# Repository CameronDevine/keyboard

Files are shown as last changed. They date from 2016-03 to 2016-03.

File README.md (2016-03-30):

#The Emoji Keyboard#

##FAQ##

If you run into any problems using the keyboard normally, please see the FAQ located [here](FAQ.md).

##Reprograming##

###Drivers###

This keyboard is an Adafruit Trinket 5V with three buttons and missing a couple of LEDs. If you would like to try to reprogram the board, the webpage [here](https://learn.adafruit.com/introducing-trinket/introduction) will guide you through installing the necessary drivers. And give a general introduction to programming the board.

###Bootloader###

Once the correct drivers are installed, and you are ready to program the board, the bootloader needs to be activated. On the Adafruit Trinket there is a button supplied for this purpose. On the keyboard there are two ways this can be done.

####Method 1####

One way to activate the bootloader is to unplug the USB cable and plug it back in. This will start the bootloader for a couple seconds before the board enters its keyboard mode.

####Method 2####

The other method is to short the reset (Rst) and ground (Gnd) pins. This second method has the exact same effect as the reset button on the Trinket.

###Libraries###

Two libraries are needed for the keyboard code to run. One is the built in EEPROM library and the other is the Trinket Keyboard library located [here](https://github.com/adafruit/Adafruit-Trinket-USB/archive/master.zip).

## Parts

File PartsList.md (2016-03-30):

#Parts List#

| location | DigiKey P/N |
|---|---|
| C1 | 732-8788-1-ND |
| D1 | 1N4148FS-ND |
| D2 | 1N4148FS-ND |
| IC1 | ATTINY85-20PU-ND |
| P1 | WM17115-ND |
| R1 | CF14JT68R0CT-ND |
| R2 | CF14JT68R0CT-ND |
| R3 | CF14JT1K50CT-ND |
| SW1 | 679-2428-ND |
| SW2 | 679-2428-ND |
| SW3 | 679-2428-ND |

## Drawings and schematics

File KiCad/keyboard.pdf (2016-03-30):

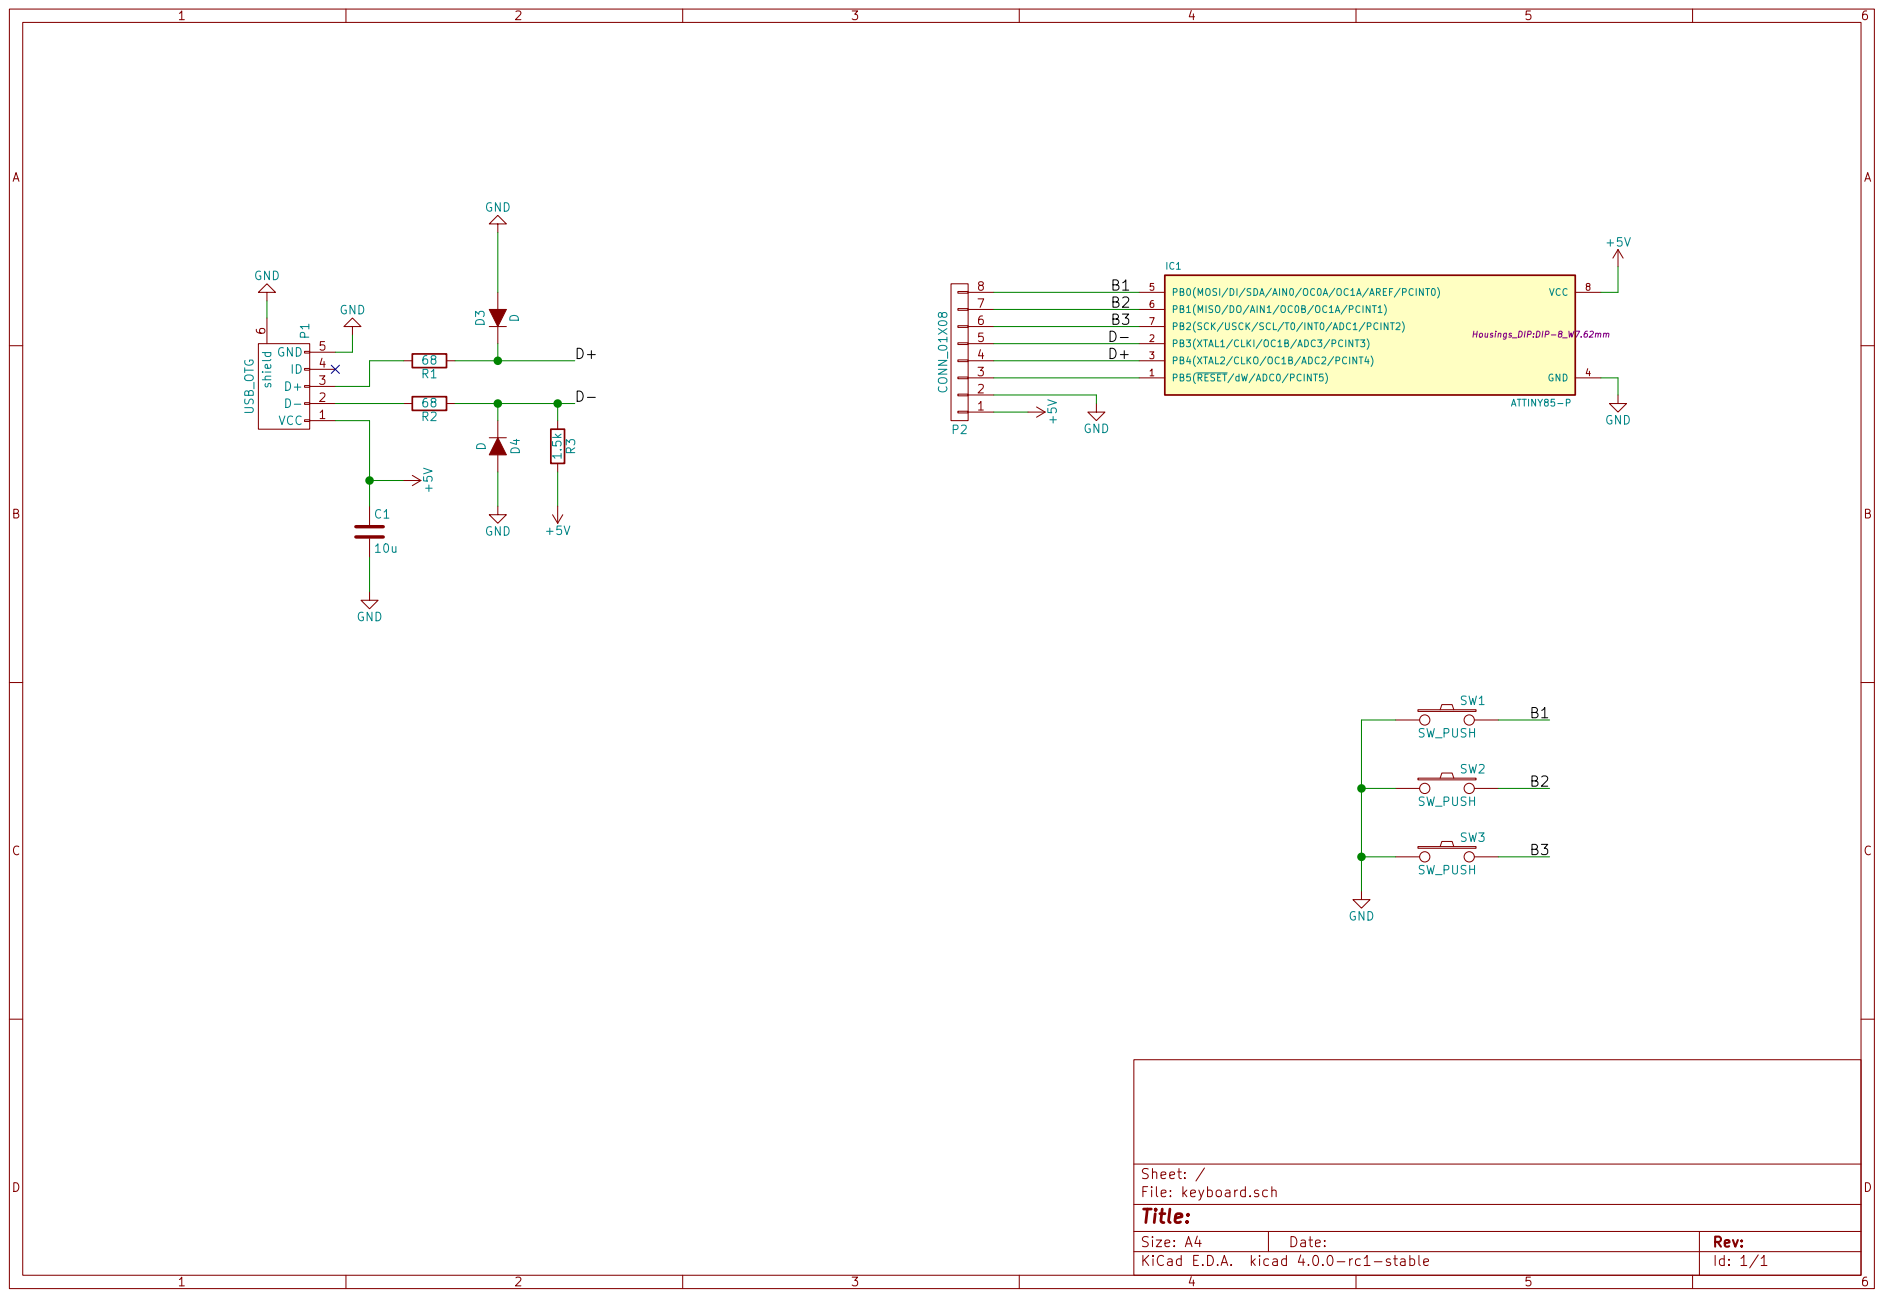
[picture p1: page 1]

File: keyboard.sch Sheet: /
Id: 1/1 Title:

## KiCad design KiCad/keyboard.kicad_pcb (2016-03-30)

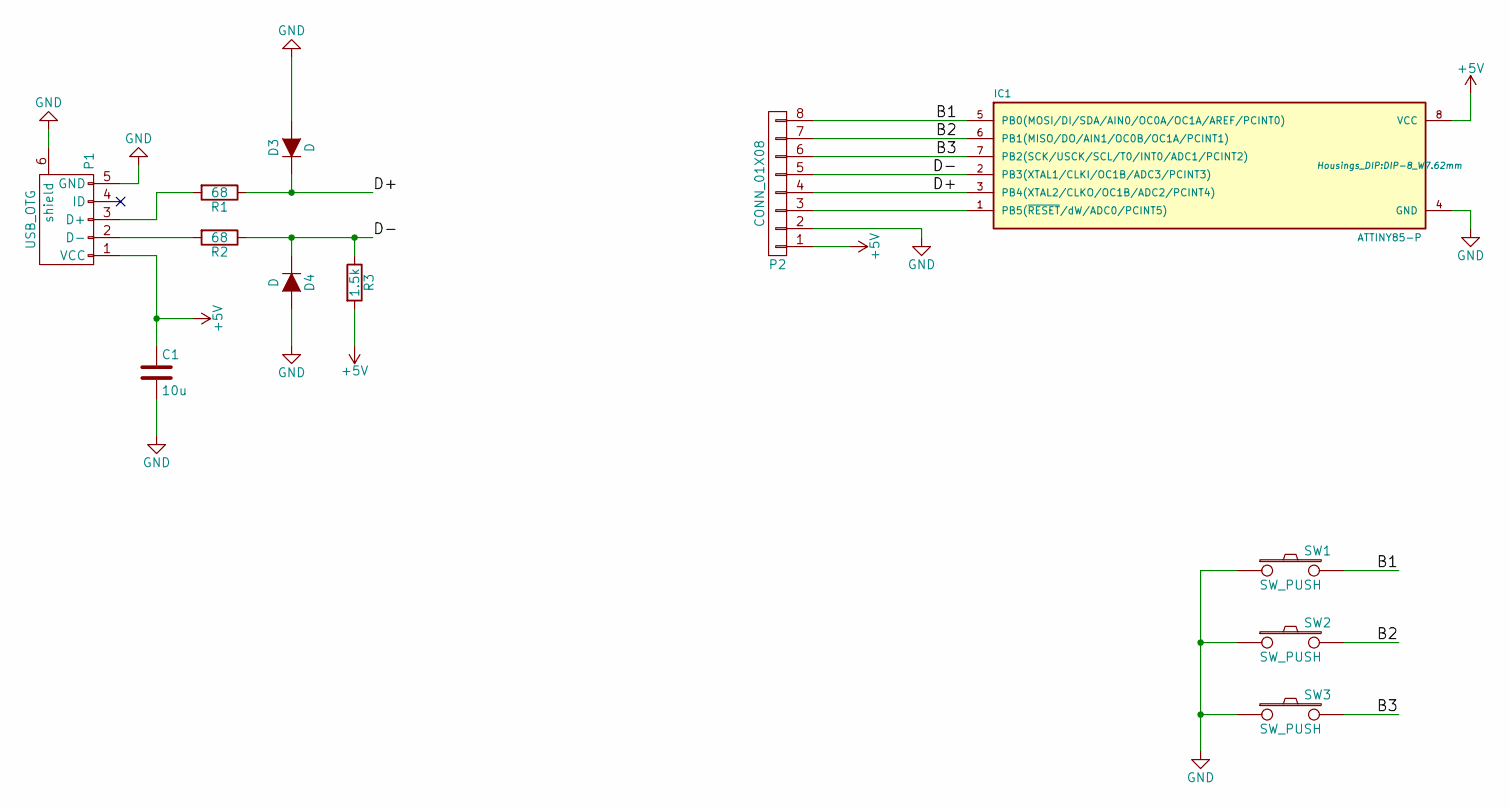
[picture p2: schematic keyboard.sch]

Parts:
C1: 10u; C_Radial_D5_L11_P2
D3, D4: D; Diode_DO-35_SOD27_Horizontal_RM10
IC1: ATTINY85-P; DIP-8_W7.62mm
P1: USB_OTG; USB
P2: CONN_01X08; Pin_Header_Straight_1x08
R1, R2: 68; Resistor_Horizontal_RM10mm
R3: 1.5k; Resistor_Horizontal_RM10mm
SW1, SW2, SW3: SW_PUSH; SW_PUSH_SMALL

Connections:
+5V: C1.1, IC1.8 (VCC), P1.1 (VCC), P2.1, R3.2
/B1: IC1.5 (PB0(MOSI/DI/SDA/AIN0/OC0A/OC1A/AREF/PCI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), P2.8, SW1.2
/B2: IC1.6 (PB1(MISO/DO/AIN1/OC0B/OC1A/PCINT1)), P2.7, SW2.2
/B3: IC1.7 (PB2(SCK/USCK/SCL/T0/INT0/ADC1/PCINT2)), P2.6, SW3.2
/D+: D3.1 (K), IC1.3 (PB4(XTAL2/CLKO/OC1B/ADC2/PCINT4)), P2.4, R1.1
/D-: D4.1 (K), IC1.2 (PB3(XTAL1/CLKI/OC1B/ADC3/PCINT3)), P2.5, R2.1, R3.1
GND: C1.2, D3.2 (A), D4.2 (A), IC1.4 (GND), P1.5 (GND), P1.6 (shield), P2.2, SW1.1, SW2.1, SW3.1
unnamed: IC1.1 (PB5(~RESET~/dW/ADC0/PCINT5)), P2.3
unnamed: P1.2 (D-), R2.2
unnamed: P1.3 (D+), R1.2

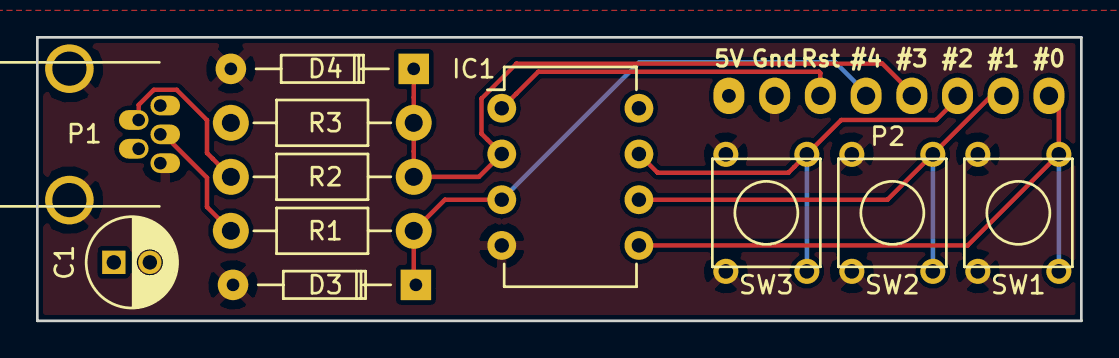
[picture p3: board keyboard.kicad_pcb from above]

Board: 2 copper layers, 58.0 x 15.8 mm, 12 parts (0 on the bottom side), 10 nets.

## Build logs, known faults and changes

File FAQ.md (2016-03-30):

#Frequently Asked Questions#

###Why does the keyboard not work until several seconds after it's plugged in?###

When the microcontroller first starts up it is in its bootloader mode. This stops automatically after a couple of seconds.

###The keyboard does not seem to be working correctly, what is wrong?###

Because of the electrical components used for the keyboard it may have issues with USB 3.0 ports. If you use a USB 2.0 post and it is still not working, try plugging it in through a USB hub. This will normally fix the issue.

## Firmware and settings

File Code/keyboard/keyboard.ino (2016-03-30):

#include <TrinketKeyboard.h>
#include <EEPROM.h>

struct Storage  {
  char left[11];
  char center[11];
  char right[11];
};

Storage storage;

void menu() {
  char button_sel;
  char text_sel[10];
  int i = 0;
  while (true) {
    if (storage.center[i] == '\0') {
      break;
    }
    else {
      backspace(1);
      i++;
    }
  }
  TrinketKeyboard.print("Entering Menu");
  while (pressed() != 'n') {
    TrinketKeyboard.poll();
  }
  backspace(13);
  TrinketKeyboard.print("Press the button you would like to change.");
  enter();
  while (pressed() == 'n')  {
    TrinketKeyboard.poll();
  }
  button_sel = pressed();
  switch (pressed())  {
    case 'l':
      TrinketKeyboard.print("left");
      break;
    case 'c':
      TrinketKeyboard.print("center");
      break;
    case 'r':
      TrinketKeyboard.print("right");
      break;
  }
  enter();
  TrinketKeyboard.print("Use the left and right buttons to select the character,\n"
  "then press the center button to confirm the selection.\n"
  "When completed select 'Done'.\n"
  "The character order is as follows:");
  enter();
  for(i=30;i<126;i++)  {
    TrinketKeyboard.print(char(i));
  }
  enter();
  enter();
  i = 0;
  int p;
  int char_i = 0;
  boolean done = false;
  while (!done)  {
    if (i == 0) {
      TrinketKeyboard.print("done");
    }
    else  {
      TrinketKeyboard.print(char(i + 31));
    }
    p = i;
    while (pressed() == 'n')  {
      TrinketKeyboard.poll();
    }
    switch (pressed())  {
      case 'l':
        i--;
        break;
      case 'r':
        i++;
        break;
      case 'c':
        if (i != 0) {
          text_sel[char_i] = char(i + 31);
          char_i++;
          i = 0;
          TrinketKeyboard.print(" ");
          if (char_i == 10) {
            text_sel[char_i] = '\0';
            done = true;
            enter();
            TrinketKeyboard.print("Maximum text length reached. ");
          }
        }
        else  {
          text_sel[char_i] = '\0';
          done = 1;
        }
    }
    while (pressed()!='n') {
      TrinketKeyboard.poll();
    }
    switch (i)  {
      case -1:
        i = 95;
        break;
      case 96:
        i = 0;
        break;
    }
    switch (p)  {
      case 0:
        backspace(4);
        break;
      default:
        backspace(1);
        break;
    }
  }
  enter();
  enter();
  TrinketKeyboard.print("Selection:  ");
  TrinketKeyboard.print(text_sel);
  enter();
  switch (button_sel)  {
    case 'l':
      strcpy(storage.left, text_sel);
      break;
    case 'c':
      strcpy(storage.center, text_sel);
      break;
    case 'r':
      strcpy(storage.right, text_sel);
      break;
  }
  EEPROM.put(0, storage);
  TrinketKeyboard.print("Saved");
}

void enter()  {
  TrinketKeyboard.pressKey(0, KEYCODE_ENTER);
  TrinketKeyboard.pressKey(0, 0);
}

void backspace(int n)  {
  for (int i = 0; i < n; i++) {
    TrinketKeyboard.pressKey(0, KEYCODE_BACKSPACE);
    TrinketKeyboard.pressKey(0, 0);
  }
}

char pressed()  {
  if (digitalRead(0)==LOW) {
    return 'l';
  }
  else if (digitalRead(1)==LOW) {
    return 'c';
  }
  else if (digitalRead(2)==LOW) {
    return 'r';
  }
  else  {
    return 'n';
  }
}

void setup() {
  digitalWrite(0,HIGH);
  digitalWrite(1,HIGH);
  digitalWrite(2,HIGH);
  EEPROM.get(0, storage);
  TrinketKeyboard.begin();
}

void loop() {
  TrinketKeyboard.poll();
  switch (pressed())  {
    case 'l':
      TrinketKeyboard.print(storage.left);
      while (pressed() == 'l') {
        TrinketKeyboard.poll();
      }
      break;
    case 'c': {
        TrinketKeyboard.print(storage.center);
        unsigned long count = millis();
        while (pressed() == 'c') {
          TrinketKeyboard.poll();
          if ((millis() - count) > 2000) {
            menu();
            break;
          }
        }
        while (pressed() == 'c') {
          TrinketKeyboard.poll();
        }
        break;
      }
    case 'r':
      TrinketKeyboard.print(storage.right);
      while (pressed() == 'r') {
        TrinketKeyboard.poll();
      }
      break;
  }
}

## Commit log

2016-03-30 adding KiCad PCB files.
    [keyboard.kicad_pcb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]
2016-03-30 adding arduino code
